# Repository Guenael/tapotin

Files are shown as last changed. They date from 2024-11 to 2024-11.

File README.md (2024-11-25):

# tapotin

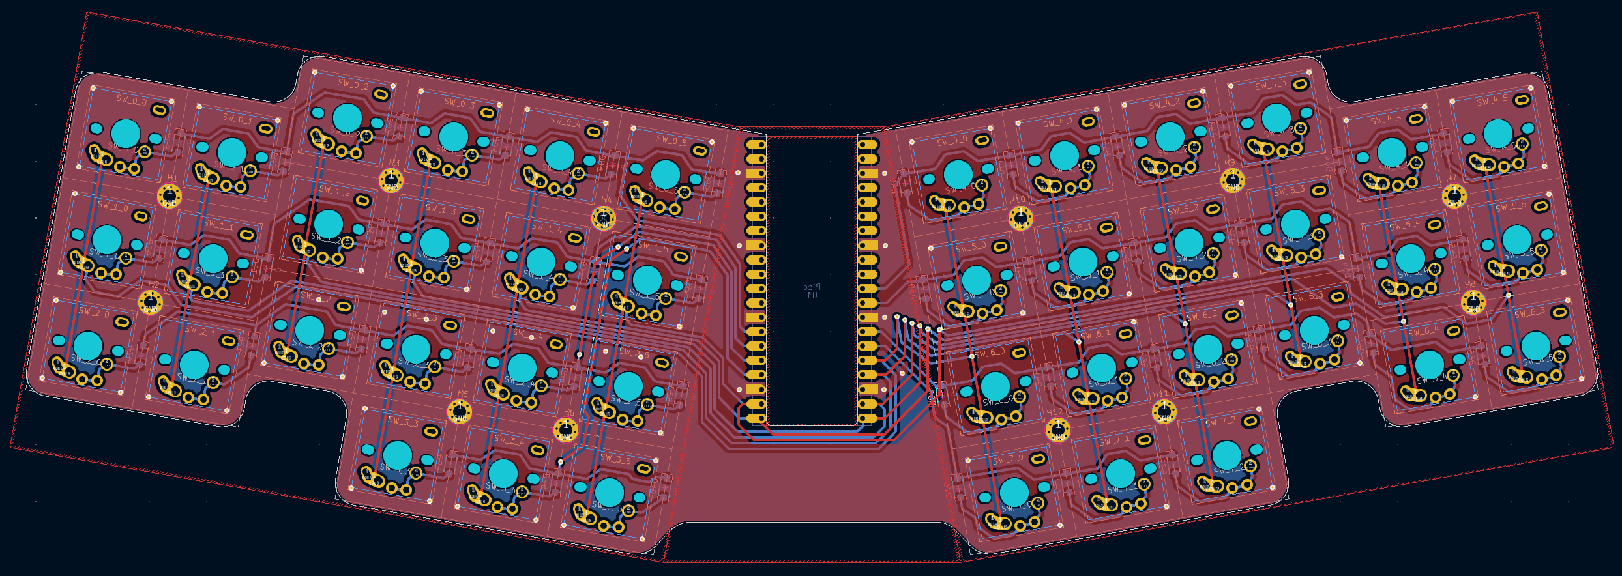
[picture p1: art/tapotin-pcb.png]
tapotin




***WORK IN PROGRESS***

# Description

Tapotin is a simple 42-keys ortho-linear keyboard, based on QMK driver and a Raspberry Pico (RP2040). The design is heavily inspired by the community, specially by [Pi5Keyboard](https://github.com/luke-schutt/Pi5Keyboard) and [chocV](https://github.com/brickbots/chocV) projects.

Kicad was used for the PCB design, and it was a nice project to switch from professional tools to a community/free PCB editor. For this first version, I used a RPi Pico board, but I plan to solder the RP2040 directly on the main PCB if I like this new keyboard.

# My requirements

- [QMK](https://qmk.fm/) based
- [RP2040](https://en.wikipedia.org/wiki/RP2040) based
- Mono-block (non-split keyboard, I tried it, and I don't like it)
- [Ortholinear](https://en.wiktionary.org/wiki/ortholinear) (offset only for the pinky)
- Left/right clear separation
- Angle 2x 10°
- 42 keys: 2*((3*6)+3)
- [Miryoku](https://github.com/manna-harbour/miryoku) layout based
- PCB specs:
  - Base/solder : 1.6mm
  - Keys plate  : 1.2mm

# Assembly

The RPi Pico board is soldered up-side down, and touch both PCB (main & key plate)

# My layout 

Here there be dragons... 20 years ago, I designed my own version of a [Dvorak layout](https://en.wikipedia.org/wiki/Dvorak_keyboard_layout), that include some requirements around programming, and accents. I like it, and I have to go all in one more time, because after 20 years, there is no way back :)

I really liked the concept of [Miryoku](https://github.com/manna-harbour/miryoku) keyboard, so I created my own version based on my custom Dvorak. One of the main difference with the original Miryoku design is that I keep an extra column for the pinky, for 3D/CAD applications with a direct access to some meta keys.

Note: Do not follow my layout, it's very specific, but if your are curious, you can check this page full of references and ideas: [Best layouts](https://www.keyboard-design.com/best-layouts.html) 

# QMK section

## Bootloader

Enter the bootloader mode by holding the RP2040 reset button down while plugging it in.

## Build

Make example for this keyboard (after setting up your build environment):

    make tapotin:default

Flashing example for this keyboard:

    make tapotin:default:flash

## Documentation

- [Build environment setup](https://docs.qmk.fm/#/getting_started_build_tools)
- [Make instructions](https://docs.qmk.fm/#/getting_started_make_guide)
- [QMK Guide](https://docs.qmk.fm/#/newbs)

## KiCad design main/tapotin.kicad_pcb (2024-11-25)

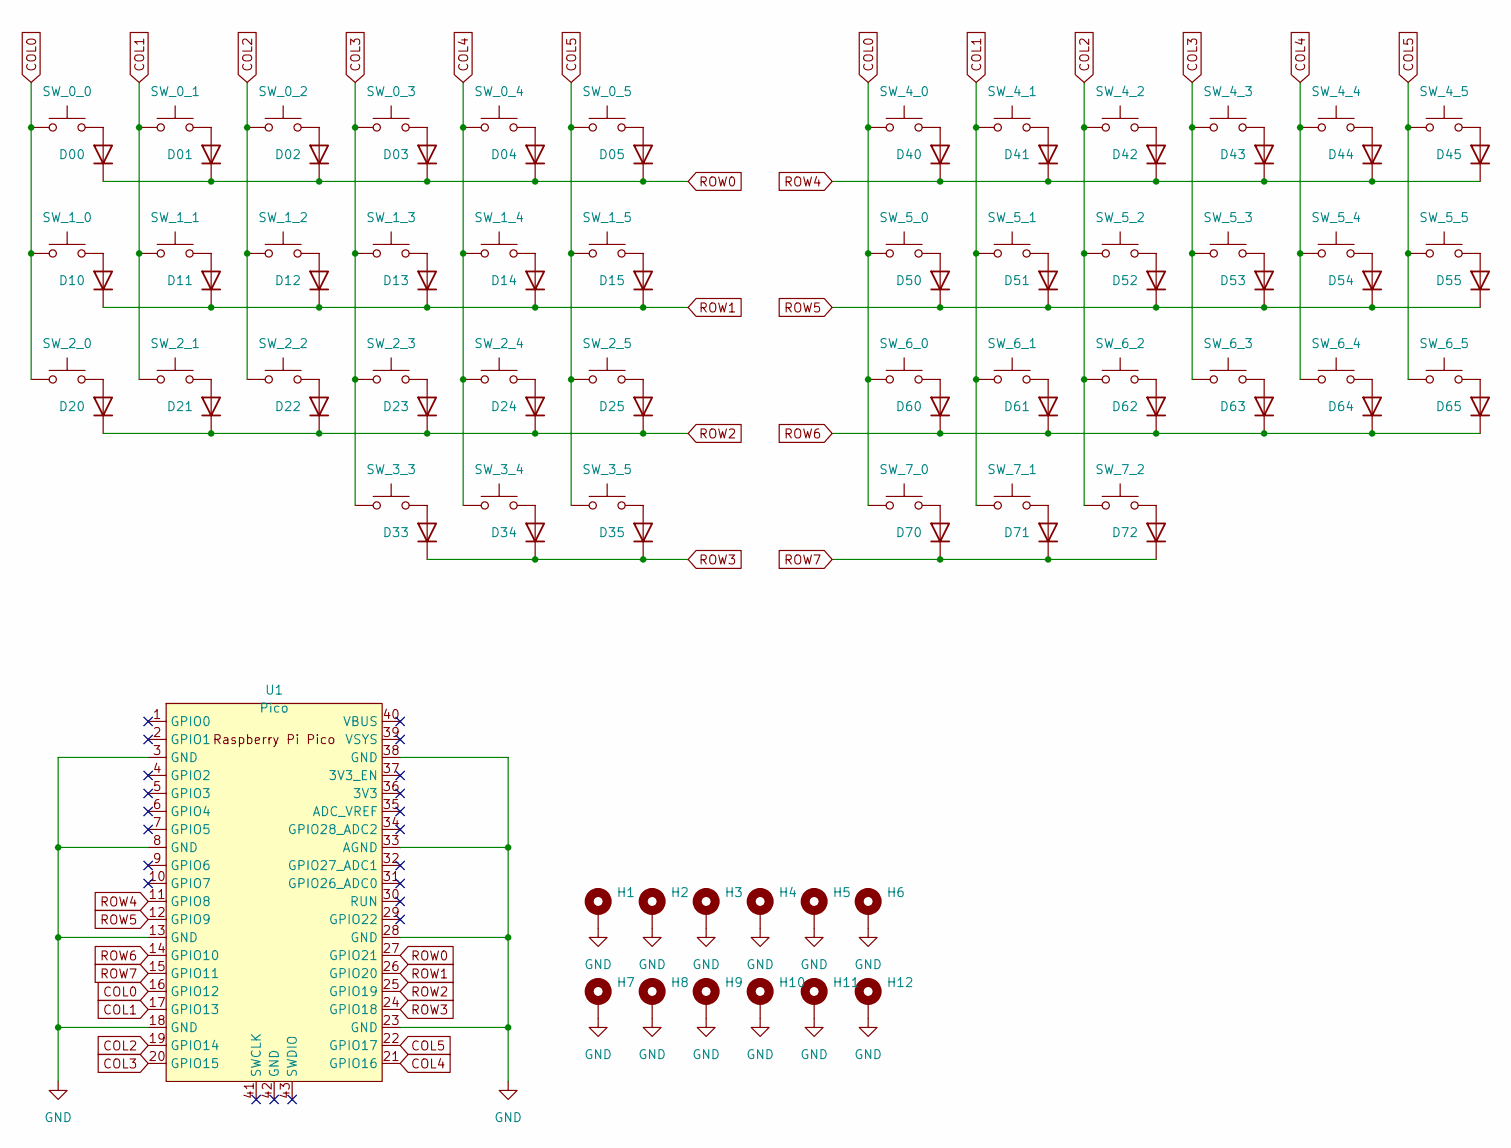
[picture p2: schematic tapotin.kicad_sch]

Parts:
D00, D01, D02, D03, D04, D05, D10, D11, D12, D13, D14, D15, D20, D21, D22, D23, D24, D25, D33, D34, D35, D40, D41, D42, D43, D44, D45, D50, D51, D52, D53, D54, D55, D60, D61, D62, D63, D64, D65, D70, D71, D72: D; my-SOD-123
H1, H2, H3, H4, H5, H6, H7, H8, H9, H10, H11, H12: MountingHole_Pad; MountingHole_2.2mm_M2_Pad_Via
SW_0_0, SW_0_1, SW_0_2, SW_0_3, SW_0_4, SW_0_5, SW_1_0, SW_1_1, SW_1_2, SW_1_3, SW_1_4, SW_1_5, SW_2_0, SW_2_1, SW_2_2, SW_2_3, SW_2_4, SW_2_5, SW_3_3, SW_3_4, SW_3_5, SW_4_0, SW_4_1, SW_4_2, SW_4_3, SW_4_4, SW_4_5, SW_5_0, SW_5_1, SW_5_2, SW_5_3, SW_5_4, SW_5_5, SW_6_0, SW_6_1, SW_6_2, SW_6_3, SW_6_4, SW_6_5, SW_7_0, SW_7_1, SW_7_2: SW_Push; SW_Multi_Profile
U1: Pico; RPi_Pico_Space

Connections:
COL0: SW_0_0.1, SW_1_0.1, SW_2_0.1, SW_4_0.1, SW_5_0.1, SW_6_0.1, SW_7_0.1, U1.16 (GPIO12)
COL1: SW_0_1.1, SW_1_1.1, SW_2_1.1, SW_4_1.1, SW_5_1.1, SW_6_1.1, SW_7_1.1, U1.17 (GPIO13)
COL2: SW_0_2.1, SW_1_2.1, SW_2_2.1, SW_4_2.1, SW_5_2.1, SW_6_2.1, SW_7_2.1, U1.19 (GPIO14)
COL3: SW_0_3.1, SW_1_3.1, SW_2_3.1, SW_3_3.1, SW_4_3.1, SW_5_3.1, SW_6_3.1, U1.20 (GPIO15)
COL4: SW_0_4.1, SW_1_4.1, SW_2_4.1, SW_3_4.1, SW_4_4.1, SW_5_4.1, SW_6_4.1, U1.21 (GPIO16)
COL5: SW_0_5.1, SW_1_5.1, SW_2_5.1, SW_3_5.1, SW_4_5.1, SW_5_5.1, SW_6_5.1, U1.22 (GPIO17)
GND: H1.1, H2.1, H3.1, H4.1, H5.1, H6.1, H7.1, H8.1, H9.1, H10.1, H11.1, H12.1, U1.3 (GND), U1.8 (GND), U1.13 (GND), U1.18 (GND), U1.23 (GND), U1.28 (GND), U1.33 (AGND), U1.38 (GND)
unnamed: D00.2 (A), SW_0_0.2
unnamed: D01.2 (A), SW_0_1.2
unnamed: D02.2 (A), SW_0_2.2
unnamed: D03.2 (A), SW_0_3.2
unnamed: D04.2 (A), SW_0_4.2
unnamed: D05.2 (A), SW_0_5.2
unnamed: D10.2 (A), SW_1_0.2
unnamed: D11.2 (A), SW_1_1.2
unnamed: D12.2 (A), SW_1_2.2
unnamed: D13.2 (A), SW_1_3.2
unnamed: D14.2 (A), SW_1_4.2
unnamed: D15.2 (A), SW_1_5.2
unnamed: D20.2 (A), SW_2_0.2
unnamed: D21.2 (A), SW_2_1.2
unnamed: D22.2 (A), SW_2_2.2
unnamed: D23.2 (A), SW_2_3.2
unnamed: D24.2 (A), SW_2_4.2
unnamed: D25.2 (A), SW_2_5.2
unnamed: D33.2 (A), SW_3_3.2
unnamed: D34.2 (A), SW_3_4.2
unnamed: D35.2 (A), SW_3_5.2
unnamed: D40.2 (A), SW_4_0.2
unnamed: D41.2 (A), SW_4_1.2
unnamed: D42.2 (A), SW_4_2.2
unnamed: D43.2 (A), SW_4_3.2
unnamed: D44.2 (A), SW_4_4.2
unnamed: D45.2 (A), SW_4_5.2
unnamed: D50.2 (A), SW_5_0.2
unnamed: D51.2 (A), SW_5_1.2
unnamed: D52.2 (A), SW_5_2.2
unnamed: D53.2 (A), SW_5_3.2
unnamed: D54.2 (A), SW_5_4.2
unnamed: D55.2 (A), SW_5_5.2
unnamed: D60.2 (A), SW_6_0.2
unnamed: D61.2 (A), SW_6_1.2
unnamed: D62.2 (A), SW_6_2.2
unnamed: D63.2 (A), SW_6_3.2
unnamed: D64.2 (A), SW_6_4.2
unnamed: D65.2 (A), SW_6_5.2
unnamed: D70.2 (A), SW_7_0.2
unnamed: D71.2 (A), SW_7_1.2
unnamed: D72.2 (A), SW_7_2.2
ROW0: D00.1 (K), D01.1 (K), D02.1 (K), D03.1 (K), D04.1 (K), D05.1 (K), U1.27 (GPIO21)
ROW1: D10.1 (K), D11.1 (K), D12.1 (K), D13.1 (K), D14.1 (K), D15.1 (K), U1.26 (GPIO20)
ROW2: D20.1 (K), D21.1 (K), D22.1 (K), D23.1 (K), D24.1 (K), D25.1 (K), U1.25 (GPIO19)
ROW3: D33.1 (K), D34.1 (K), D35.1 (K), U1.24 (GPIO18)
ROW4: D40.1 (K), D41.1 (K), D42.1 (K), D43.1 (K), D44.1 (K), D45.1 (K), U1.11 (GPIO8)
ROW5: D50.1 (K), D51.1 (K), D52.1 (K), D53.1 (K), D54.1 (K), D55.1 (K), U1.12 (GPIO9)
ROW6: D60.1 (K), D61.1 (K), D62.1 (K), D63.1 (K), D64.1 (K), D65.1 (K), U1.14 (GPIO10)
ROW7: D70.1 (K), D71.1 (K), D72.1 (K), U1.15 (GPIO11)

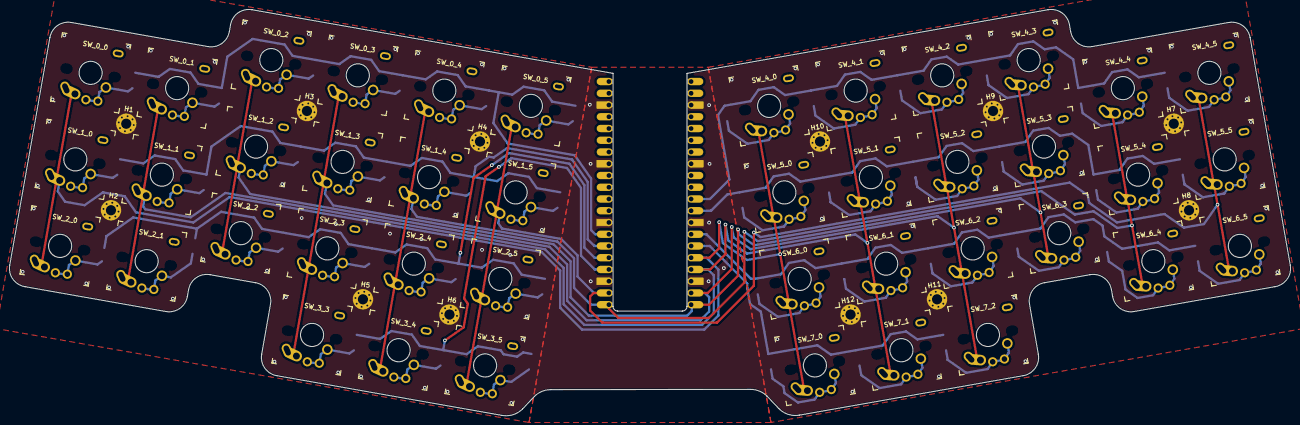
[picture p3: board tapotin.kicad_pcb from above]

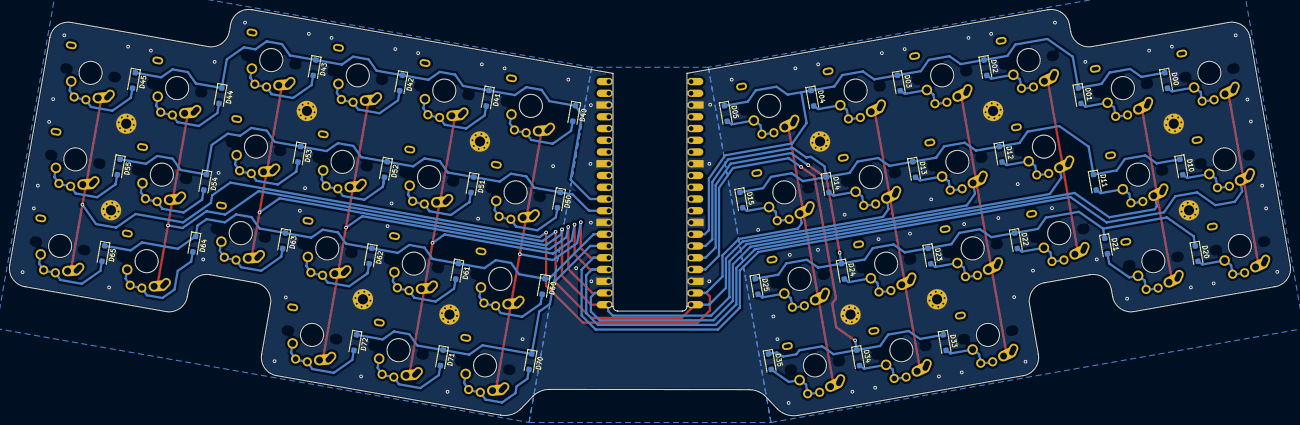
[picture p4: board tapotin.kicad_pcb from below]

Board: 2 copper layers, 277.0 x 87.9 mm, 97 parts (43 on the bottom side), 57 nets.

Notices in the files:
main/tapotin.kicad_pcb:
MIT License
